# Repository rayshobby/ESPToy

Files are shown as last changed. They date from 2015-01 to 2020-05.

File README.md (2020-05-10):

ESPToy
======

ESPToy is an open-source development board for the ESP8266 WiFi module

- v1 has an on-board avr (atmega644) microcontroller which communicates with an external ESP8266-01 module through serial.

- v1.2x has built-in ESP12 WiFi chip, color LED, button, LiPo battery jack and charging chip, microUSB connector and CH340G USB-serial. Its demo program is in arduino/v1.2x folder. Uploading new program requires bootloading procedure (i.e. hold the on-board button while plugging in USB to enter bootloading mode).

- v2.0 has added auto reset circuit (eliminating bootloading procedure), changed LED to WS2812 (Neopixel) type, added a mini buzzer, light sensor and solder jumper to enable/disable the sensor. Its demo program is in arduino/v2.0 folder. V2.0 is fully compatible with LOLIN Wemos D1 Mini.

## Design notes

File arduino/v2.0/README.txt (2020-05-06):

This folder contains Arduino demo code for
ESPtoy v2 new version (with built-in ESP-12
module, buzzer, and Neopixel color led).

To compile the code, use Arduino installed
with ESP8266 core files:
https://github.com/esp8266/Arduino

Alternatively, use Makefile:
https://github.com/plerup/makeEspArduino

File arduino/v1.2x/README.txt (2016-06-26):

This folder contains Arduino demo code for
ESPtoy v2 (with built-in ESP-12 module).

To compile the code, use Arduino installed
with ESP8266 core files:
https://github.com/esp8266/Arduino

Alternatively, use Makefile:
https://github.com/plerup/makeEspArduino

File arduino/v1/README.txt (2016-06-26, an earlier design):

This folder contains Arduino code for ESPtoy v1
(with ATmega644 MCU + ESP8266 module). The code
uses ATmega644 to send AT commands to ESP8266.

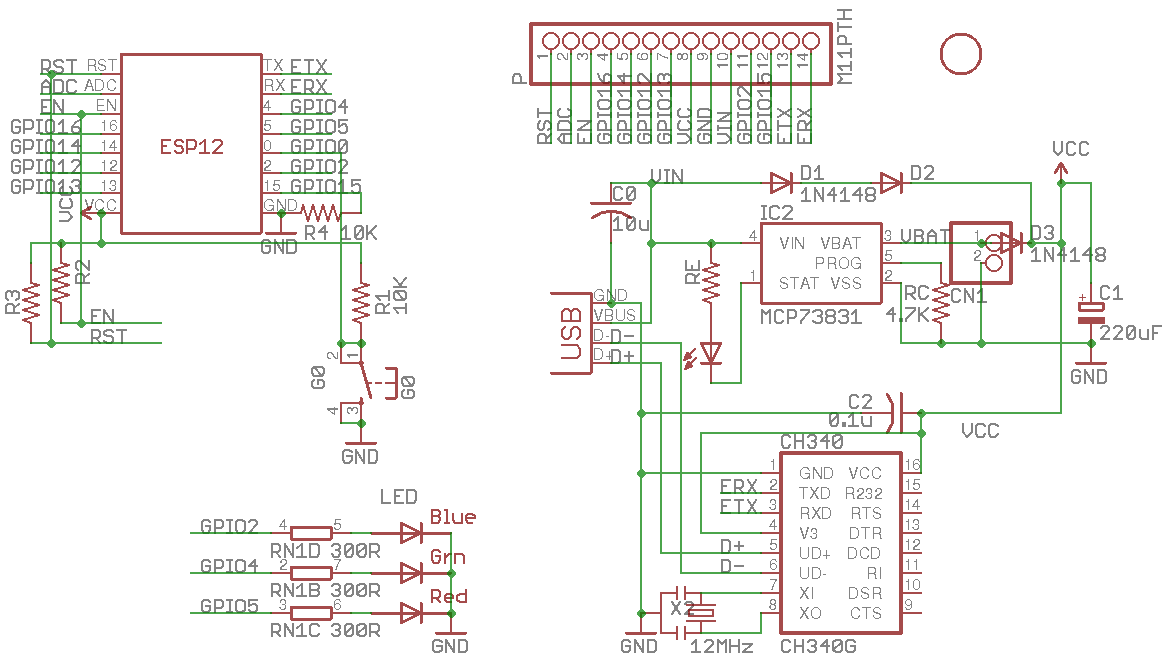
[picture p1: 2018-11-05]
schematic/esptoy_v13.png

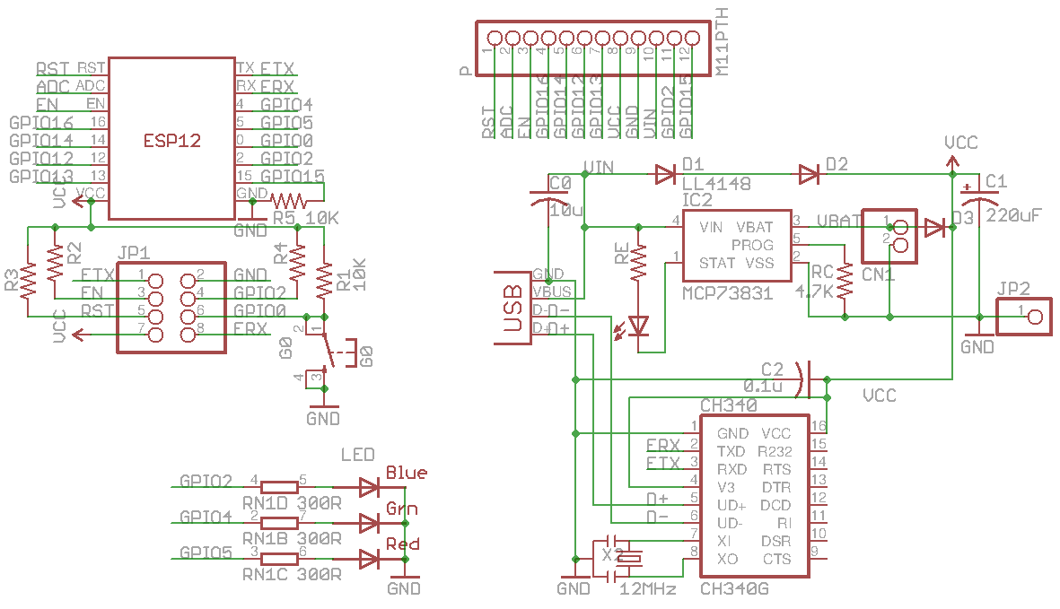
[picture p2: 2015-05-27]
schematic/esptoy_v122.png

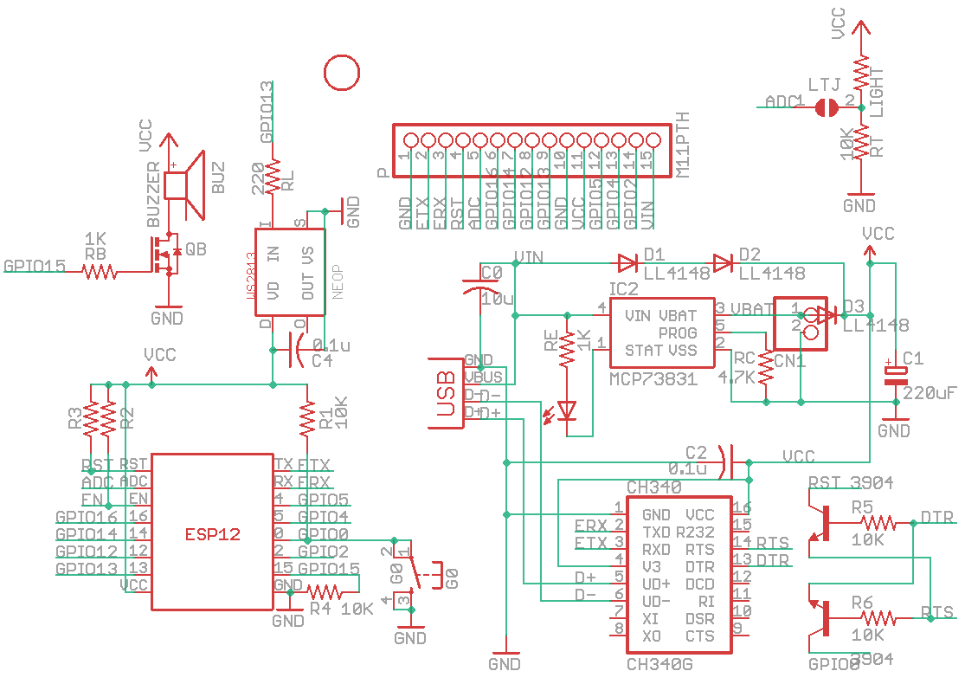
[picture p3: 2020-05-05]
schematic/esptoy_v200.png

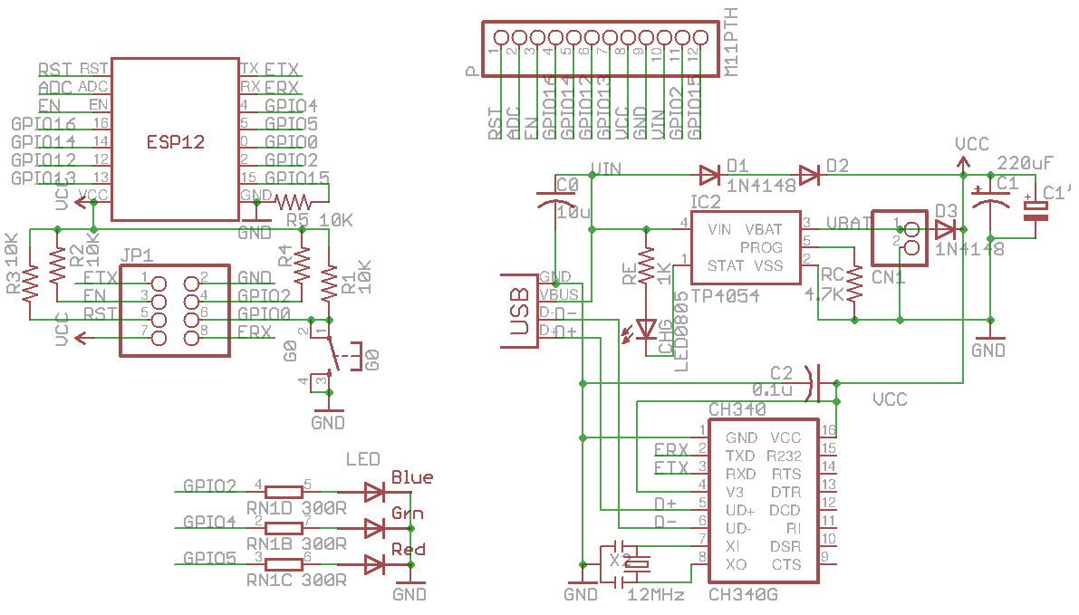
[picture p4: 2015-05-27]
schematic/esptoy_v123.png

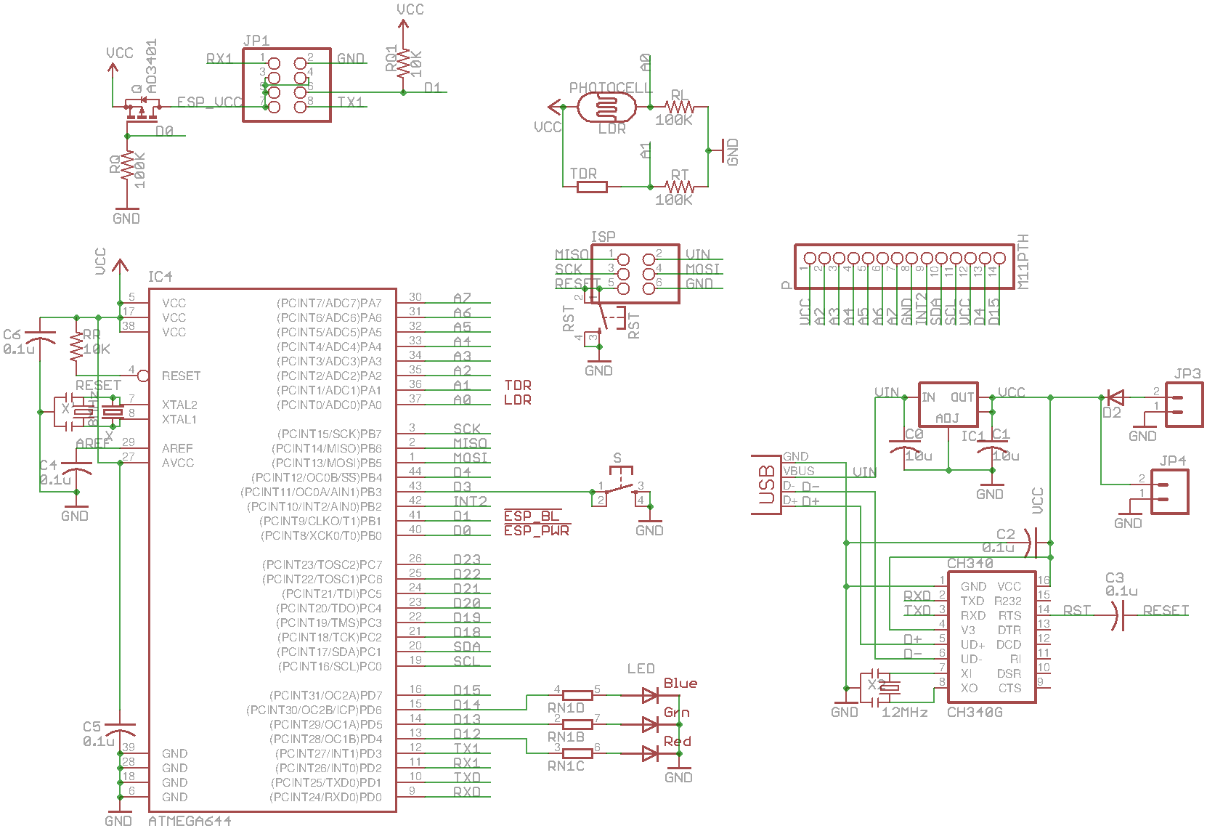
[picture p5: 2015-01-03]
schematic/esptoy_v1.png

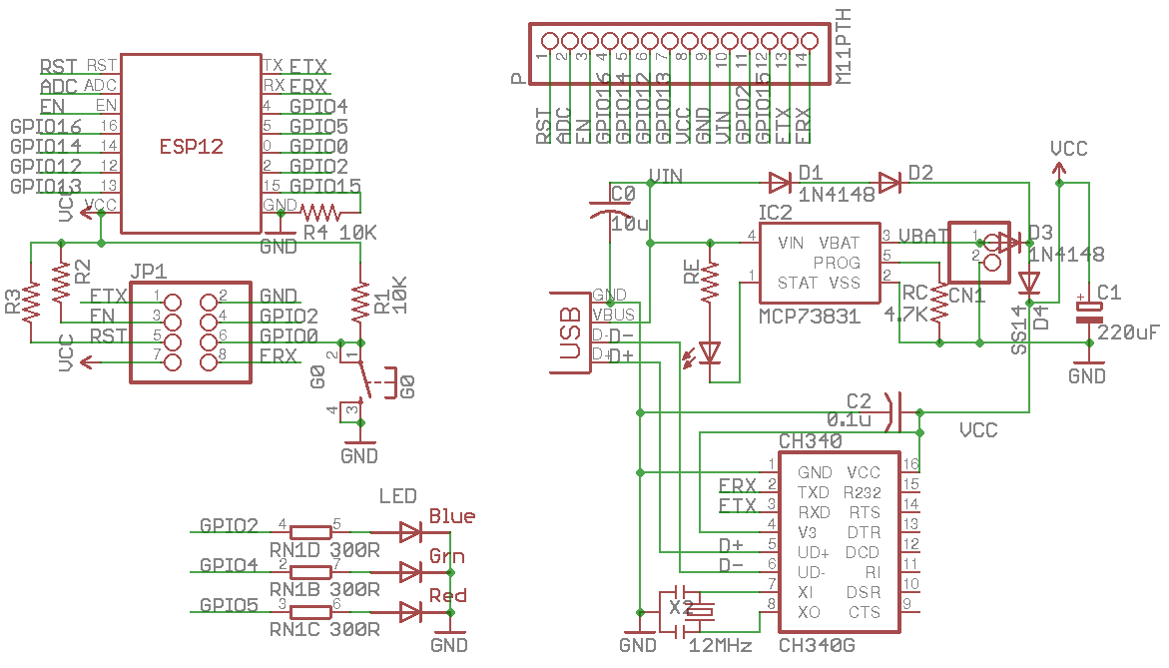
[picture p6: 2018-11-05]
schematic/esptoy_v124.png

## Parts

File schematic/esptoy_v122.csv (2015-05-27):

Part | Value | Device | Package | Notes | Example Part
C0 | 10u | C-USC0805K | SMD 0805 | General-purpose 10uF 0805 ceramic cap | http://www.digikey.com/product-detail/en/CC0805ZKY5V5BB106/311-1462-1-ND/2833768
C1 | 220uF | CAP_POL3528-KIT | EIA3528-KIT | Use either C1 (tan cap) or C1' (electro cap)
C1' |  | CPOL-EUD | PANASONIC_D
C2 | 0.1u | C-USC0603K | SMD 0603 | General-purpose 0.1uF (104) 0603 ceramic cap
CH340 | CH340G | CH340G | SO16 | USB-serial chip, SOIC-16
CHG | LED0805 | LEDCHIPLED_0805 | CHIPLED_0805 | General-purpose LED 0805
CN1 |  | JST_2PIN-SMT-RA | JST-PH-2-SMT-RA | LiPo battery jack 2.0mm
D1 | LL4148 | DIODE-MINIMELF | MINIMELF | General-purpose SMD diode, any type
D2 | LL4148 | DIODE-MINIMELF | MINIMELF
D3 | LL4148 | DIODE-MINIMELF | MINIMELF
G0 | G0 | TAC_SWITCHSMD | TACTILE_SWITCH_SMD | 4.5mmx4.5mm SMD tactile button
IC2 | TP4054 | MCP73831 | SOT23-5 | LiPo charger TP4054 or MCP73831/MCP73832, interchangeable | http://www.digikey.com/product-detail/en/MCP73832T-2DCI%2FOT/MCP73832T-2DCI%2FOTCT-ND/1979807
JP1 |  | PINHD-2X4 | 2X04 | For ESP-1, backward compatible
LED | RGBLED5050 | RGBLED5050 | RGBLED5050 | 5mmx5mm RGB LED | http://www.digikey.com/product-detail/en/SMP6-RGB/492-1268-1-ND/2407201
P | M11PTH | PINHD-1X12-CB | 1X12-CB
R1 | 10K | R-US_R0603 | R0603 | General-purpose 10K 0603 5% resistor
R2 | 10K | R-US_R0603 | R0603
R3 | 10K | R-US_R0603 | R0603
R4 | 10K | R-US_R0603 | R0603
R5 | 10K | R-US_R0603 | R0603
RC | 4.7K | R-US_R0805 | R0805 | General-purpose 4.7K 0805 5% resistor
RE | 1K | R-US_R0603 | R0603 | General-purpose 1K 0603 5% resistor
RN1 | 300R | 4R-NEXB38V | EXB38V | 300 ohm x 4 resistor network (1206, 0603x4) | http://www.digikey.com/product-detail/en/YC164-JR-07300RL/YC164J-300CT-ND/1005667
U$1 |  | ESP12 | ESP12 | ESP-12 or ESP-7 module
X2 | 12MHz | RESONATORSMD | RESONATOR-SMD | 12MHz resonator | http://www.digikey.com/product-detail/en/CSTCE12M0G52-R0/490-8579-1-ND/4380179
X3 | USB mini | USB mini | USB mini | Mini-USB SMD | http://www.digikey.com/product-detail/en/10033526-N3212LF/609-4700-1-ND/4292063

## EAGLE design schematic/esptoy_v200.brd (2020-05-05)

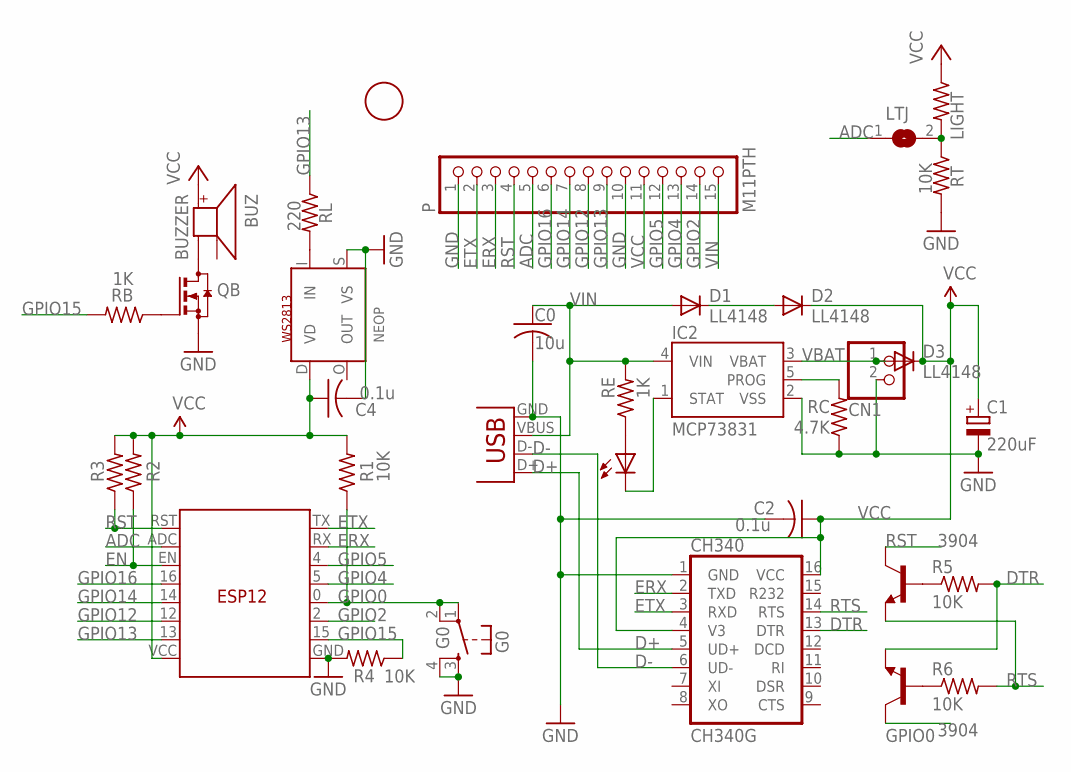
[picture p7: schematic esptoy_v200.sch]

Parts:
1F: FIDUCIAL; FIDUCIAL_1MM
BUZ: BUZZER; SMT-8585-BUZZER
C0: 10u; C0805K
C1: 220uF; CT3528
C2, C4: 0.1u; C0603K
CH340: CH340G; SO16
CHG: 0805; CHIPLED_0805
CN1: JST_2PIN-SMT-RA; JST-PH-2-SMT-RA
D1, D2, D3: LL4148; DO-214AC
G0: G0; TACTILE_SWITCH_SMD
IC2: MCP73831; SOT23-5
LIGHT: 100K; R1206
LTJ: SJ
NEOP: WS2813; RGBLED5050_4
P: M11PTH; 1X15-CB
QB: AO3400; SOT23
R1, R2, R3, R4, R5, R6: 10K; R0603
RB: 1K; R0603
RC: 4.7K; R0603
RE: 1K; R0603
RL: 220; R0603
RT: 10K; R0603
T1, T2: 3904; SOT23-BEC
U$1: ESP8266; ESP12
X3: USBMICROB2; USB-MICROB2

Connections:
ADC: LTJ.1, P.5, U$1.ADC
ADC1: LIGHT.2, LTJ.2, RT.1
D+: CH340.5 (UD+), X3.D+
D-: CH340.6 (UD-), X3.D-
DTR: CH340.13 (DTR), R5.2, T2.E
EN: R2.1, U$1.EN
ERX: CH340.2 (TXD), P.3, U$1.RX
ETX: CH340.3 (RXD), P.2, U$1.TX
GND: C0.2, C1.-, C2.2, C4.2, CH340.1 (GND), CN1.2 (1), G0.3, G0.4, IC2.2 (VSS), NEOP.S (VS), P.1, P.10, QB.2 (S), R4.2, RC.1, RT.2, U$1.GND, X3.GND
GPIO0: G0.1, G0.2, R1.1, T2.C, U$1.0 (G0)
GPIO2: P.14, U$1.2 (G2)
GPIO4: P.13, U$1.5 (G5)
GPIO5: P.12, U$1.4 (G4)
GPIO12: P.8, U$1.12 (G12)
GPIO13: P.9, RL.1, U$1.13 (G13)
GPIO14: P.7, U$1.14 (G14)
GPIO15: R4.1, RB.2, U$1.15 (G15)
GPIO16: P.6, U$1.16 (G16)
unnamed: D1.C, D2.A
unnamed: R5.1, T1.B
unnamed: IC2.5 (PROG), RC.2
unnamed: CHG.A, RE.1
unnamed: CHG.C, IC2.1 (STAT)
unnamed: R6.1, T2.B
unnamed: BUZ.-, QB.3 (D)
unnamed: QB.1 (G), RB.1
unnamed: NEOP.I (IN), RL.2
RST: P.4, R3.1, T1.C, U$1.RST
RTS: CH340.14 (RTS), R6.2, T1.E
VBAT: CN1.1 (2), D3.A, IC2.3 (VBAT)
VCC: BUZ.+, C1.+, C2.1, C4.1, CH340.4 (V3), CH340.16 (VCC), D2.C, D3.C, LIGHT.1, NEOP.D (VD), P.11, R1.2, R2.2, R3.2, U$1.VCC
VIN: C0.1, D1.A, IC2.4 (VIN), P.15, RE.2, X3.VBUS

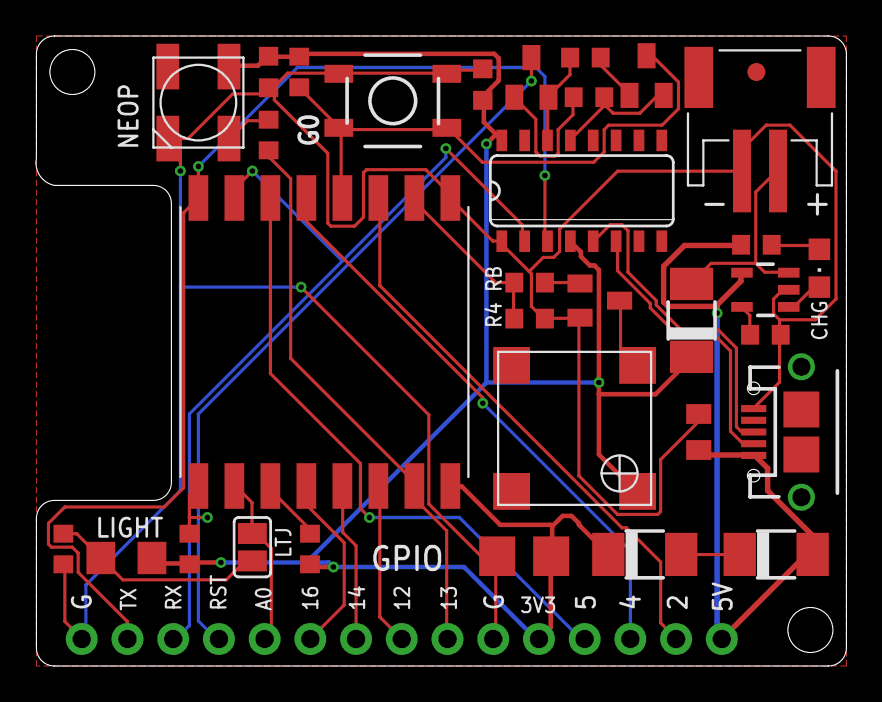
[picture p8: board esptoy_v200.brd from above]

Board: 2 copper layers, 45.0 x 35.0 mm, 34 parts (0 on the bottom side), 32 nets.

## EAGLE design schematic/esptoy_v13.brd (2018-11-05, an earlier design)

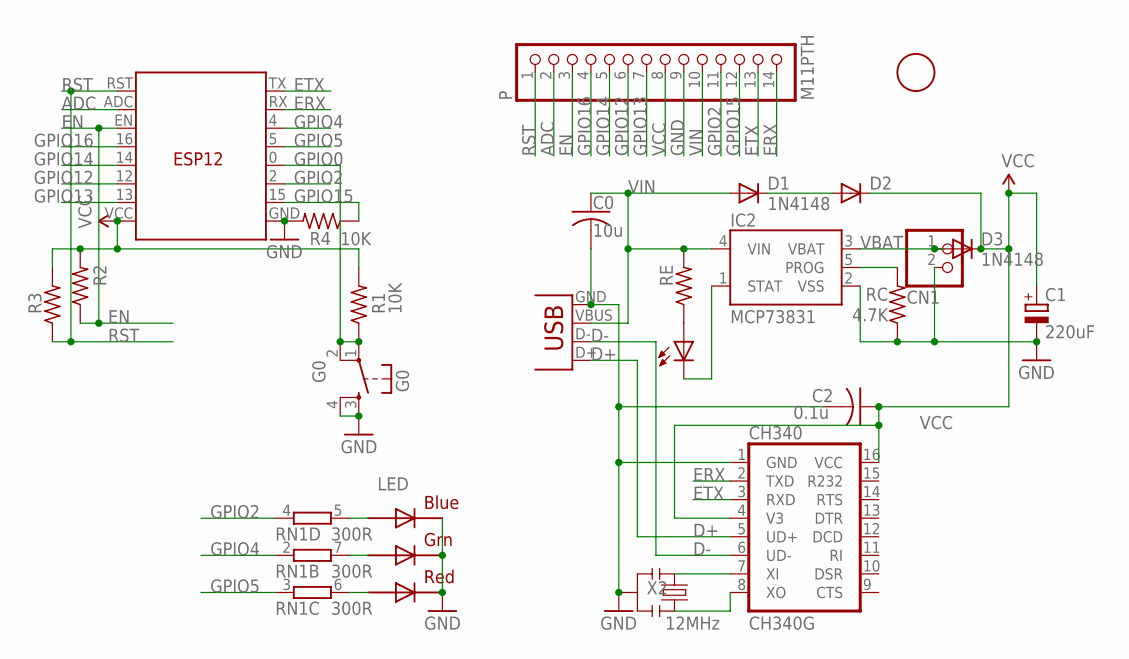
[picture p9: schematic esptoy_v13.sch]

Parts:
1F: FIDUCIAL; FIDUCIAL_1MM
C0: 10u; C0805K
C1: 220uF; CT3528
C2: 0.1u; C0603K
CH340: CH340G; SO16
CHG: 0805; CHIPLED_0805
CN1: JST_2PIN-SMT-RA; JST-PH-2-SMT-RA
D1, D3: 1N4148; DO-214AC
D2: DIODE-DO-214AC; DO-214AC
G0: G0; TACTILE_SWITCH_SMD
IC2: MCP73831; SOT23-5
LED: RGBLED5050
P: M11PTH; 1X14-CB
R1, R4: 10K; R0603
R2, R3: R-US_R0603; R0603
RC: 4.7K; R0603
RE: R-US_R0603; R0603
RN1: 300R; EXB38V
U$1: ESP12
X2: 12MHz; RESONATOR-SMD
X3: USBMICROB2; USB-MICROB2

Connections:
ADC: P.2, U$1.ADC
D+: CH340.5 (UD+), X3.D+
D-: CH340.6 (UD-), X3.D-
EN: P.3, R2.1, U$1.EN
ERX: CH340.2 (TXD), P.14, U$1.RX
ETX: CH340.3 (RXD), P.13, U$1.TX
GND: C0.2, C1.-, C2.2, CH340.1 (GND), CN1.2 (1), G0.3, G0.4, IC2.2 (VSS), LED.4 (BLUE_C), LED.5 (RED_C), LED.6 (GREEN_C), P.9, R4.2, RC.1, U$1.GND, X2.2, X3.GND
GPIO0: G0.1, G0.2, R1.1, U$1.0 (G0)
GPIO2: P.11, RN1.4 (1), U$1.2 (G2)
GPIO4: RN1.2 (1), U$1.4 (G4)
GPIO5: RN1.3 (1), U$1.5 (G5)
GPIO12: P.6, U$1.12 (G12)
GPIO13: P.7, U$1.13 (G13)
GPIO14: P.5, U$1.14 (G14)
GPIO15: P.12, R4.1, U$1.15 (G15)
GPIO16: P.4, U$1.16 (G16)
unnamed: D1.C, D2.A
unnamed: LED.3 (BLUE_A), RN1.5 (2)
unnamed: IC2.5 (PROG), RC.2
unnamed: CHG.A, RE.1
unnamed: CHG.C, IC2.1 (STAT)
unnamed: LED.1 (GREEN_A), RN1.7 (2)
unnamed: LED.2 (RED_A), RN1.6 (2)
unnamed: CH340.7 (XI), X2.1
unnamed: CH340.8 (XO), X2.3
RST: P.1, R3.1, U$1.RST
VBAT: CN1.1 (2), D3.A, IC2.3 (VBAT)
VCC: C1.+, C2.1, CH340.4 (V3), CH340.16 (VCC), D2.C, D3.C, P.8, R1.2, R2.2, R3.2, U$1.VCC
VIN: C0.1, D1.A, IC2.4 (VIN), P.10, RE.2, X3.VBUS

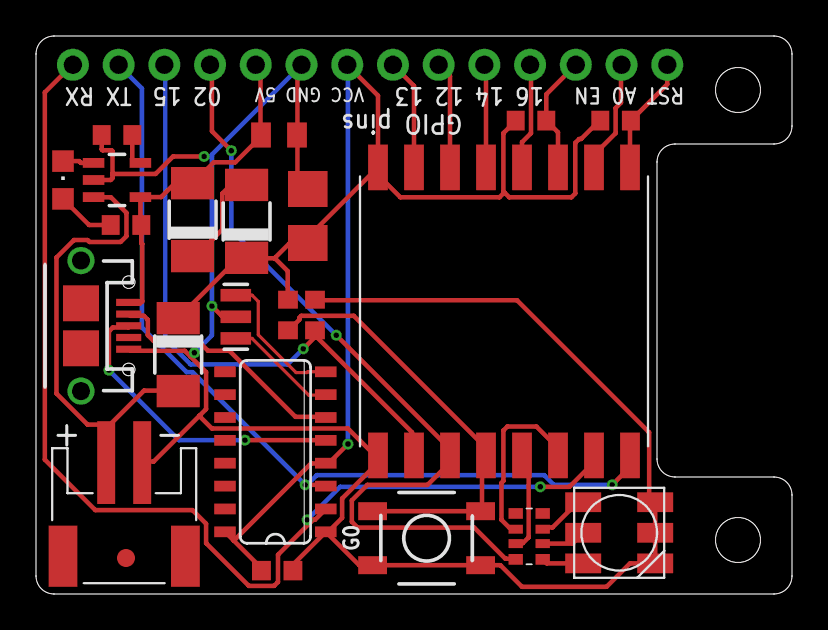
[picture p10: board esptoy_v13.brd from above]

Board: 2 copper layers, 42.0 x 31.0 mm, 24 parts (0 on the bottom side), 29 nets.

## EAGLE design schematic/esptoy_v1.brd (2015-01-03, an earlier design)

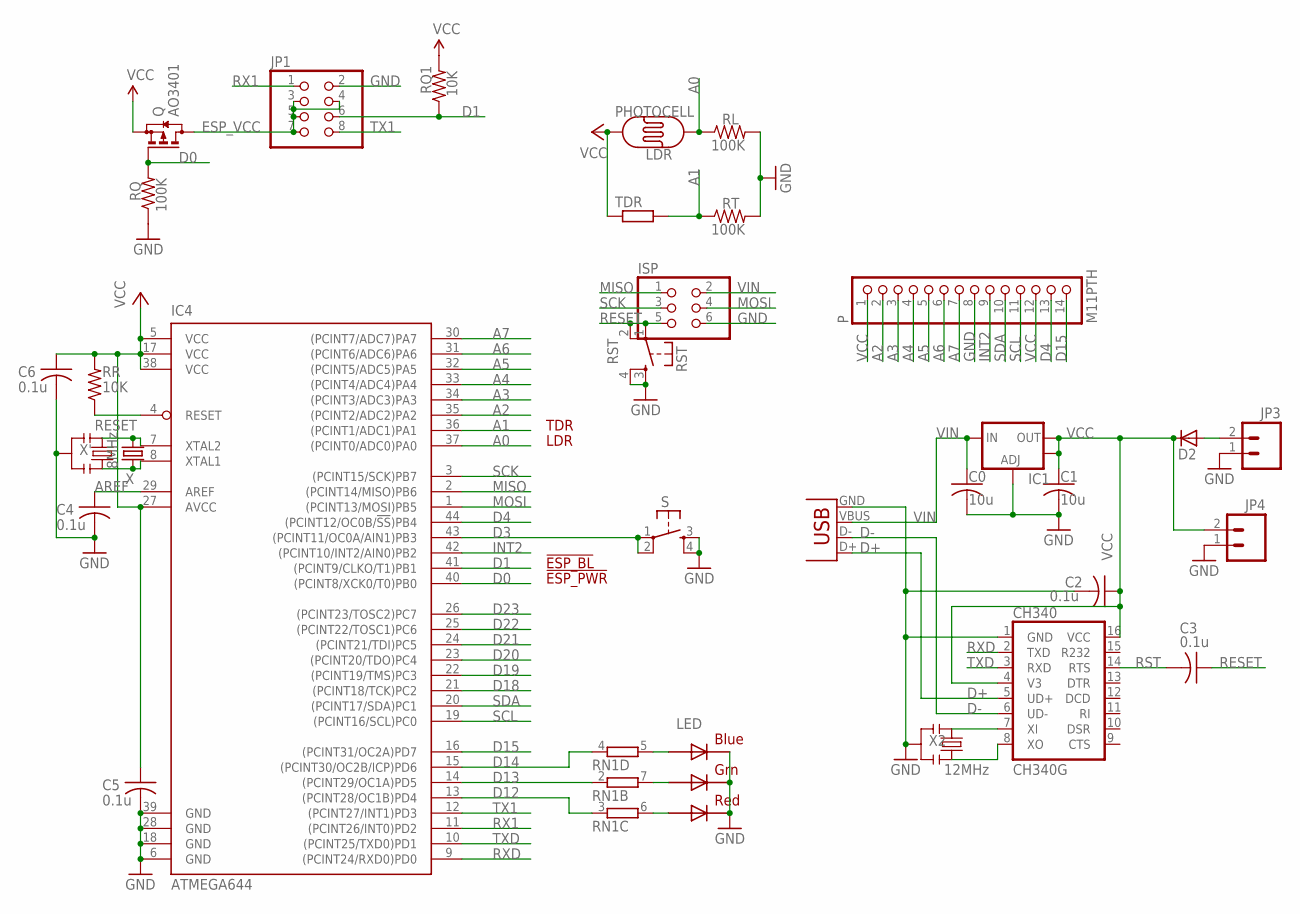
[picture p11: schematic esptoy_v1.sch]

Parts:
C0, C1: 10u; C0805K
C2, C3, C4, C6: 0.1u; C0603
C5: 0.1u; C0603K
CH340: CH340G; SO16
D2: DIODESMA; SMA-DIODE
IC1: V_REG_LM1117SOT223; SOT223
IC4: ATMEGA644; TQFP44
ISP: PINHD-2X3; 2X03
JP1: PINHD-2X4; 2X04
JP3: M02-JST-2MM-SMT; S2B-PH
JP4: M02PTH; 1X02
LDR: PHOTOCELL
LED: RGBLED5050
P: M11PTH; 1X14-CB
Q: AO3401; SOT23
RL: 100K; R0805
RN1: 4R-NEXB38V; EXB38V
RQ: 100K; R0805
RQ1: 10K; R0603
RR: 10K; R0603
RST: RST; TACTILE_SWITCH_SMD
RT: 100K; R0805
S: TAC_SWITCHSMD; TACTILE_SWITCH_SMD
TDR: R-EU_V526-0; V526-0
X: 8MHz; TC26V
X1: USBSMD; USB-MINIB
X2: 12MHz; RESONATOR-SMD
X': 12MHz; RESONATOR-SMD

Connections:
A0: IC4.37 ((PCINT0/ADC0)PA0), LDR.1, RL.1
A1: IC4.36 ((PCINT1/ADC1)PA1), RT.1, TDR.2
A2: IC4.35 ((PCINT2/ADC2)PA2), P.2
A3: IC4.34 ((PCINT3/ADC3)PA3), P.3
A4: IC4.33 ((PCINT4/ADC4)PA4), P.4
A5: IC4.32 ((PCINT5/ADC5)PA5), P.5
A6: IC4.31 ((PCINT6/ADC6)PA6), P.6
A7: IC4.30 ((PCINT7/ADC7)PA7), P.7
AREF: C4.1, IC4.29 (AREF)
D0: IC4.40 ((PCINT8/XCK0/T0)PB0), Q.1 (G), RQ.2
D1: IC4.41 ((PCINT9/CLKO/T1)PB1), JP1.6, RQ1.1
D3: IC4.43 ((PCINT11/OC0A/AIN1)PB3), S.1, S.2
D4: IC4.44 ((PCINT12/OC0B/!SS!)PB4), P.13
D12: IC4.13 ((PCINT28/OC1B)PD4), RN1.3 (1)
D13: IC4.14 ((PCINT29/OC1A)PD5), RN1.2 (1)
D14: IC4.15 ((PCINT30/OC2B/ICP)PD6), RN1.4 (1)
D15: IC4.16 ((PCINT31/OC2A)PD7), P.14
D18: IC4.21 ((PCINT18/TCK)PC2)
D19: IC4.22 ((PCINT19/TMS)PC3)
D20: IC4.23 ((PCINT20/TDO)PC4)
D21: IC4.24 ((PCINT21/TDI)PC5)
D22: IC4.25 ((PCINT22/TOSC1)PC6)
D23: IC4.26 ((PCINT23/TOSC2)PC7)
D+: CH340.5 (UD+), X1.D+
D-: CH340.6 (UD-), X1.D-
ESP_VCC: JP1.3, JP1.4, JP1.5, JP1.7, Q.3 (D)
GND: C0.2, C1.2, C2.2, C4.2, C5.2, C6.2, CH340.1 (GND), IC1.1 (ADJ), IC4.6 (GND), IC4.18 (GND), IC4.28 (GND), IC4.39 (GND), ISP.6, JP1.2, JP3.1, JP4.1, LED.4 (BLUE_C), LED.5 (RED_C), LED.6 (GREEN_C), P.8, RL.2, RQ.1, RST.3, RST.4, RT.2, S.3, S.4, X1.GND, X2.2, X'.2
INT2: IC4.42 ((PCINT10/INT2/AIN0)PB2), P.9
MISO: IC4.2 ((PCINT14/MISO)PB6), ISP.1
MOSI: IC4.1 ((PCINT13/MOSI)PB5), ISP.4
unnamed: D2.A, JP3.2
unnamed: LED.3 (BLUE_A), RN1.5 (2)
unnamed: LED.1 (GREEN_A), RN1.7 (2)
unnamed: LED.2 (RED_A), RN1.6 (2)
unnamed: CH340.7 (XI), X2.1
unnamed: CH340.8 (XO), X2.3
unnamed: IC4.7 (XTAL2), X.2, X'.1
unnamed: IC4.8 (XTAL1), X.1, X'.3
RESET: C3.1, IC4.4 (RESET), ISP.5, RR.1, RST.1, RST.2
RST: C3.2, CH340.14 (RTS)
RX1: IC4.11 ((PCINT26/INT0)PD2), JP1.1
RXD: CH340.2 (TXD), IC4.9 ((PCINT24/RXD0)PD0)
SCK: IC4.3 ((PCINT15/SCK)PB7), ISP.3
SCL: IC4.19 ((PCINT16/SCL)PC0), P.11
SDA: IC4.20 ((PCINT17/SDA)PC1), P.10
TX1: IC4.12 ((PCINT27/INT1)PD3), JP1.8
TXD: CH340.3 (RXD), IC4.10 ((PCINT25/TXD0)PD1)
VCC: C1.1, C2.1, C5.1, C6.1, CH340.4 (V3), CH340.16 (VCC), D2.C, IC1.2 (OUT), IC1.4 (OUT), IC4.5 (VCC), IC4.17 (VCC), IC4.27 (AVCC), IC4.38 (VCC), JP4.2, LDR.2, P.1, P.12, Q.2 (S), RQ1.2, RR.2, TDR.1
VIN: C0.1, IC1.3 (IN), ISP.2, X1.VBUS

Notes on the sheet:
TDR
LDR
!ESP_PWR
!ESP_BL

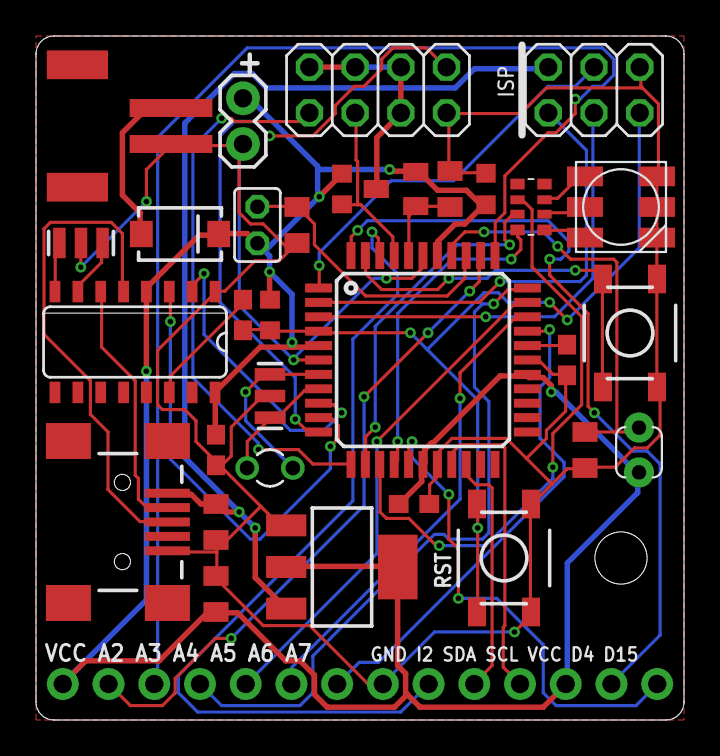
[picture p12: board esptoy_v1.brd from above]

Board: 2 copper layers, 36.0 x 38.0 mm, 32 parts (0 on the bottom side), 43 nets.

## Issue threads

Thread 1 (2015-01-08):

board name incorrect in boards.txt file

deepcoder, 2015-01-08:
The line in the boards.txt file:

esptoy.name=OpenSprinklerHW2.2 (16MHz, Serial)

seems to have the wrong name for the board, according to this blog post:

http://rayshobby.net/?p=10156

the board name should be 'ESPToy'

'Next, launch the Arduino IDE, select Tools->Board->ESPToy,'

rayshobby, 2015-01-08:
You are right, the board name should be ESPToy. I just updated it. Thanks

Closed 2015-01-08.

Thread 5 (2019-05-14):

Missing version 1.3?

xaque208, 2019-05-14:
I'm just starting to play around and having a hard time with the v2 demo printing to serial after flashing.  Perhaps I've got the board set incorrectly to NodeMCU ESP-12.  It was pretty much the only ESP-12 in my list.

xaque208, 2019-05-14:
I see the file `schematic/esptoy_v13.sch` so perhaps this is just my issue.

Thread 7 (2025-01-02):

ESPHome support

mightymos, 2025-01-02:
I thought this would be a good board for interacting with Home Assistant by way of ESPHome.
The yaml file to allow using all the sensors, lights, buzzer is honestly pretty simple.

Nevertheless, would you accept a pull request for an example yaml that supports ESPToy?
Or possibly a link to another repo?

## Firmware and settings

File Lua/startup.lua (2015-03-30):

r=0
g=0
b=0
pin_red=2
pin_green=1
pin_but=3
pin_blue=4
p=0
gpio.mode(pin_but, gpio.INPUT, gpio.PULLUP)
pwm.setup(pin_red, 100, 0)
pwm.setup(pin_green,100,0)
pwm.setup(pin_blue,100, 0)
pwm.start(pin_red)
pwm.start(pin_green)
pwm.start(pin_blue)
wifi.setmode(wifi.SOFTAP)
cfg={}
cfg.ssid="ESPToy" .. (string.sub(wifi.ap.getmac(), 15,17))
cfg.pwd="opendoor"
wifi.ap.config(cfg)

srv=net.createServer(net.TCP, 1)
srv:listen(80,function(conn) 
     conn:on("receive",function(conn,payload) 
          if string.match(payload, " / ") then
               p=1
               print("Serve homepage")
               conn:send("<!DOCTYPE html><html> <head> <title>ESPToy Demo</title> <meta name='viewport' content='width=device-width, initial-scale=1'> </head> <body> <div> <h3>ESPToy Demo</h3> <hr> <div> <table cellpadding=2> <script>function w(s){document.write(s);}function id(s){return document.getElementById(s);}</script> <tr><td><b>Analog</b>:</td><td><label id='lbl_adc'></label></td></tr><tr><td><b>Button</b>:</td><td><label id='lbl_but'></label></td></tr><tr><td><b>Red</b>:</td><td><input type='range' id='s_r' value=0 min=0 max=255></input></td></tr><tr><td><b>Green</b>:</td><td><input type='range' id='s_g' value=0 min=0 max=255></input></td></tr><tr><td><b>Blue</b>:</td><td><input type='range' id='s_b' value=0 min=0 max=255></input></td></tr></table> <div> <button id='btn_ref' onclick='loadValues()'>Refresh Values</button> <button id='btn_sub' onclick='setColor()'>Set Color</button> </div></div></div><script>var devip='http://192.168.4.1';")
          end
          if string.match(payload, " /ja ") then
               p=2
               conn:send("{\"adc\":" .. adc.read(0) .. ",\"but\":" .. (1-gpio.read(pin_but)) .. ",\"red\":" .. r .. ",\"green\":" .. g .. ",\"blue\":" .. b .. "}")
          end
          if string.match(payload, " /cc?") then
               print("Received request to change color")
               local val=string.match(payload,"r=(%d+)")
               if val then
                    r=tonumber(val)
               end
               local val=string.match(payload,"g=(%d+)")
               if val then
                    g=tonumber(val)
               end
               local val=string.match(payload,"b=(%d+)")
               if val then
                    b=tonumber(val)
               end
               print("Heap size: " .. node.heap())          
               pwm.setduty(pin_red, r)
               pwm.setduty(pin_green, g)
               pwm.setduty(pin_blue, b)
               
          end
     end) 
     conn:on("sent",function(conn) 
          if p==1 then
               p=2
               conn:send(" function loadValues(){var xmlhttp; if(window.XMLHttpRequest) xmlhttp=new XMLHttpRequest(); else xmlhttp=new ActiveXObject('Microsoft.XMLHTTP'); xmlhttp.onreadystatechange=function(){if(xmlhttp.readyState==4 && xmlhttp.status==200){var jd=JSON.parse(xmlhttp.responseText); id('lbl_adc').innerHTML=jd.adc; id('lbl_but').innerHTML=(jd.but)?'pressed':'released'; id('s_r').value=jd.red; id('s_g').value=jd.green; id('s_b').value=jd.blue;}}; xmlhttp.open('GET',devip+'/ja',true); xmlhttp.send();}function setColor(){var xmlhttp; if(window.XMLHttpRequest) xmlhttp=new XMLHttpRequest(); else xmlhttp=new ActiveXObject('Microsoft.XMLHTTP'); xmlhttp.open('GET',devip+'/cc?'+'r='+id('s_r').value+'&g='+id('s_g').value+'&b='+id('s_b').value,true); xmlhttp.send();}setTimeout(loadValues, 500); </script> </body></html>")
          else
               p=0
               conn:close()
          end
     end)
end)

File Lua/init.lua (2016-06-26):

-- ESPToy Startup Demo
-- This requires file 'esptoy.htm' to exist on the ESP8266 module. Upload the file if it doesn't exist

-- Set up GPIO pins
r=0
g=0
b=0
pin_red=2
pin_green=4
pin_but=3
pin_blue=1
gpio.mode(pin_but, gpio.INPUT, gpio.PULLUP)
pwm.setup(pin_red, 100, 512)
pwm.setup(pin_green,100,512)
pwm.setup(pin_blue,100, 0)
pwm.start(pin_red)
pwm.start(pin_green)
pwm.start(pin_blue)
tmr.delay(200000)
pwm.setduty(pin_red,0)
pwm.setduty(pin_green,0)
pwm.setduty(pin_blue,0)

-- Set up WiFi
wifi.setmode(wifi.SOFTAP)
cfg={}
cfg.ssid="ESPToy" .. (string.sub(wifi.ap.getmac(), 15,17))
cfg.pwd="opendoor"
wifi.ap.config(cfg)

if srv then
  srv:close()
end
srv=net.createServer(net.TCP, 3)
srv:listen(80,function(conn) 
  conn:on("receive", function(conn,payload)
    local isOpen=false
    conn:on("sent", function(conn)
      if not isOpen then
        isOpen=true
        file.open(fileName, 'r')
      end
      local data=file.read(1024)
      if data then
        conn:send(data)
      else
        file.close()
        conn:close()
        conn=nil
      end
    end)
    
    if string.sub(payload, 1, 6) == 'GET / ' then
      fileName = 'esptoy.htm'
      conn:send("HTTP/1.1 200 OK\r\n")
      conn:send("Content-type: text/html\r\n")
      conn:send("Connection: close\r\n\r\n")
    elseif string.sub(payload, 1, 8) == 'GET /ja ' then
      conn:send("HTTP/1.1 200 OK\r\n")
      conn:send("Content-type: application/json\r\n")
      conn:send("Connection: close\r\n\r\n")
      conn:send("{\"adc\":" .. adc.read(0) .. ",\"but\":" .. (1-gpio.read(pin_but)) .. ",\"red\":" .. r .. ",\"green\":" .. g .. ",\"blue\":" .. b .. "}")
      conn:close()
      conn=nil
    elseif string.sub(payload, 1, 8) == 'GET /cc?' then
      conn:close()
      conn=nil

      local val=string.match(payload,"r=(%d+)")
      if val then
        r=tonumber(val)
      end
      local val=string.match(payload,"g=(%d+)")
      if val then
        g=tonumber(val)
      end
      local val=string.match(payload,"b=(%d+)")
      if val then
        b=tonumber(val)
      end
      pwm.setduty(pin_red, r)
      pwm.setduty(pin_green, g)
      pwm.setduty(pin_blue, b)
    else
      conn:close()
    end
  end) 
end)

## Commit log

2015-01-03 initial check in of ESPToy Arduino library and hardware design files
    [esptoy_v1.brd, esptoy_v1.sch]
2015-01-08 correct board name
2015-01-09 fix Arduino compiler stack overflow issue (by breaking long strings into shorter ones. seems like an Arduino bug.
2015-04-24 add esptoy 1.21 schematic and Eagle files
    [esptoy_v12.brd, esptoy_v12.sch]
2015-05-27 add part list, add esptoy 1.22 schematic and board design
    [esptoy_v122.brd, esptoy_v122.csv, esptoy_v122.sch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]
2015-05-27 update part list
    [esptoy_v122.csv]
2016-06-26 move esptoy v1 arduino code to v1 folder, add new v2 folder
2016-06-26 add new Default Demo based on Arduino ESP8266 core
2018-11-05 add v1.24 schematic and board design
    [esptoy_v124.brd, esptoy_v124.sch]
2018-11-05 add version 1.3 schematic and board design.
    [esptoy_v13.brd, esptoy_v13.sch]
2020-05-05 check in ESPToy v2.0 schematic
    [esptoy_v200.brd, esptoy_v200.sch]

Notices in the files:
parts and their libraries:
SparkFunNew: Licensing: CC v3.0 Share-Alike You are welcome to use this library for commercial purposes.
